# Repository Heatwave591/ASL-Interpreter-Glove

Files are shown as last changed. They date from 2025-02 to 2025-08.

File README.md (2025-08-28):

**Project Goals:**
* Design an American Sign Language (ASL) interpreting glove that converts sign language to English and outputs the translation.
* Recognize and translate the entire ASL alphabet.
* Identify and process basic static signs.
* Design a PCB for the circuit.

**Necessary Equipment and Sensors:**
* [ESP32 microcontroller x 2](https://www.amazon.com/HiLetgo-ESP-WROOM-32-Development-Microcontroller-Integrated/dp/B0718T232Z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)
* [Flex sensors x 15](https://www.amazon.com/dp/B00LP25V1A?ref=ppx_yo2ov_dt_b_fed_asin_title&th=1)
* [MPU6050 x 2](https://www.amazon.com/dp/B0BLGT1F5F?ref=ppx_yo2ov_dt_b_fed_asin_title)
* [Pair of gloves x 1](https://www.amazon.com/Cotton-Gloves-Handling-Inspection-Photography/dp/B07ZMXNCQ5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)

  Note - The links for the products are embedded in the text. Clicking the link will redirect you to amazon.com.

# Project Description
The ASL-interpreting glove will be designed to detect hand gestures and translate them into spoken words and a visual interface output. The system will consist of flex sensors to track finger movements, MPU6050 sensors for motion detection, and ESP32 microcontrollers to process and transmit data to an output system.
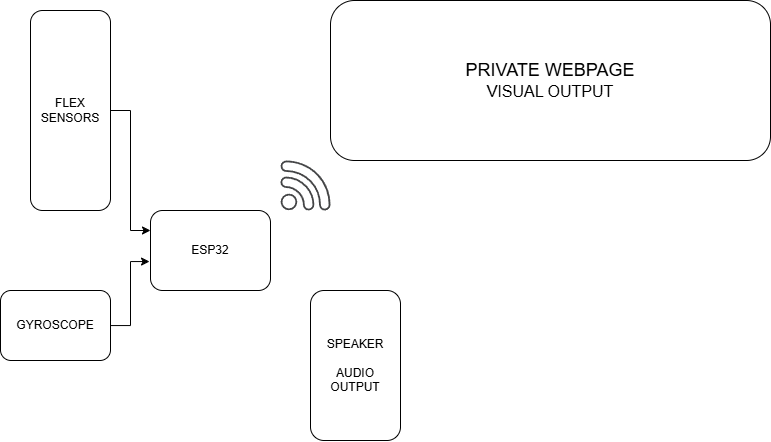
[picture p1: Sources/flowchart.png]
Glove Prototype


# System Setup
### Hardware
- The hardware consists of five flex sensors and an IMU in each hand
- The flex sensors need to be connected to the analog pins of the ESP32. Make sure to choose the correct pins according to your circuit.
	- All the ESP32 models do not have analog pins. If that happens, check the datasheet of the ESP32 and use the ADC pins instead and you should be good to go.
	- Many ESP32 boards have the issue of some pins being rendered useless when the wifi module is on. If the pin that is needed is being used by wifi, then, you have no choice other than using a different pin.
	
- The flex sensors need to create a conventional voltage divider circuit with the same value of resistors across all sensors (We have used the 10KOhm Resistor).
- The IMU follows a straight forward serial connection. 
	- Connect the power rails together
	- Connect the Serial Clock and the Serial Data of the IMU to the Serial Clock and Serial Data of the ESP32 respectively
- This concludes the hardware setup of the glove.

### Software 
The software consists of 4 parts.
- Arduino IDE Setup
- Firebase Setup
- Arduino Execution 
- HTML Setup and Execution

#### Arduino IDE Setup
- Download the Arduino IDE.
- Open the IDE.
- To make the ESP32 compatable, go to File > Preferences
- Paste this link in the Additional Board Manager URL's box
	- "https://raw.githubusercontent.com/espressif/arduino-esp32/gh-pages/package_esp32_index.json"
- Restart the IDE
- Go to Boards Manager and download the ESP32 package.
- Install the following libraries.
	- WiFi.h
	- Firebase_ESP_Client.h
	- Adafruit mpu6050
	- Adafruit Unified Sensor
	- Adafruit BusIO

- We will be using 2 scripts in this approach, but technically, there are many scripts in the repository that follow different methods that result in the same results.
- The process that we followed for this project is to essentially fetch data from the sensors, package the data into a JSON file, send it to a Firebase server and have the HTML file scrap data from there.

#### Firebase Setup
- Open Firebase in your browser.
- Login using your Google account.
- Go to Console.
- Create a new Firebase Project.
- Name your Project whatever you want. We have called it "ASL-Interpreter-Glove"
- Follow the instruction on screen and create the project.
- Enter the project.
- In the right side, Navigate to Product Categories > Build > Realtime Database.
- This is where our data will be seen.
- The link that is seen on top is our "DATABASE_URL". We will need this.
- Go to the project settings on the top right corner of the page.
- We will need the "API_KEY".
- This concludes the firebase setup. Missing out on any of these steps will result in the code not working.

#### Arduino Execution
- Open up the Arduino Editor.
- Since we have 2 gloves, we will have to upload and run 2 different codes on 2 ESP32s. But first, some modifications must be made to the code so that it will be compatible with the computer and the server.
- The changes are the same for both the codes.
- Set up the wifi network in the code
	- I have put placeholder values for the SSID and passwords for safety. This needs to be changed prior to running.
	- Replace WIFI_SSID and WIFI_PASSWORD with your credentials. Make sure that the network is in the 2.4GHz band 
	- Replace API_KEY and DATABASE_URL with the information we got from the firebase server.
- Once all of this is done, the code is ready to be dumped in the ESP32
- For the left hand and up and load [Firebase_Flex_Left.ino](Firebase%20Stuff/Firebase_Flex_Right/Firebase_Flex_Right.ino)
- Do the same with [Firebase_Flex_Right.ino](Firebase%20Stuff/Firebase_Flex_Right/Firebase_Flex_Right.ino) for the ESP32 that goes on the Right hand.

#### HTML Setup and Execution
- Once the server is up and running, We will have to setup the webpage where the inferences will be shown.
- Download the [webserver.html](webserver.html) file.
- Make the changes in lines 192, 193, 194 with the API_KEY, DATABASE_URL and PROJECT_ID.
- Now, host the file with python. (Note that you will not need a separate python script to do this. It can be done in the python interactive terminal by following these setps)
	- Go to the file directory and open a python interactive terminal.
	- Run this code  ``` python3 -m SimpleHTTPServer 3000```
	- This will locally host the webpage.
	- Open the web browser and type ```localhost:3000 ```
	- The port used here is 3000, this can be changed to any other port too.

# Machine Learning Model Interpretation
- The machine learning model runs by taking data out of the serial ports.
- When the ESP32 is executing the code, close all the serial monitors and then run the python sctript [INT_model_inference.py](Interpretation/INT_model_inference.py).
- This will run the machine learning model and send inferences to the webpage.

# Possible Future Works
* Support for dynamic signs.
* Integration of two gloves for improved accuracy.

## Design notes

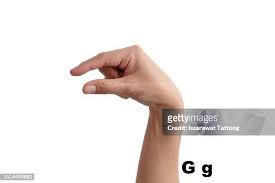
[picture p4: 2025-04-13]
Submissions/Final/Final Video/srcs/gg.jpeg

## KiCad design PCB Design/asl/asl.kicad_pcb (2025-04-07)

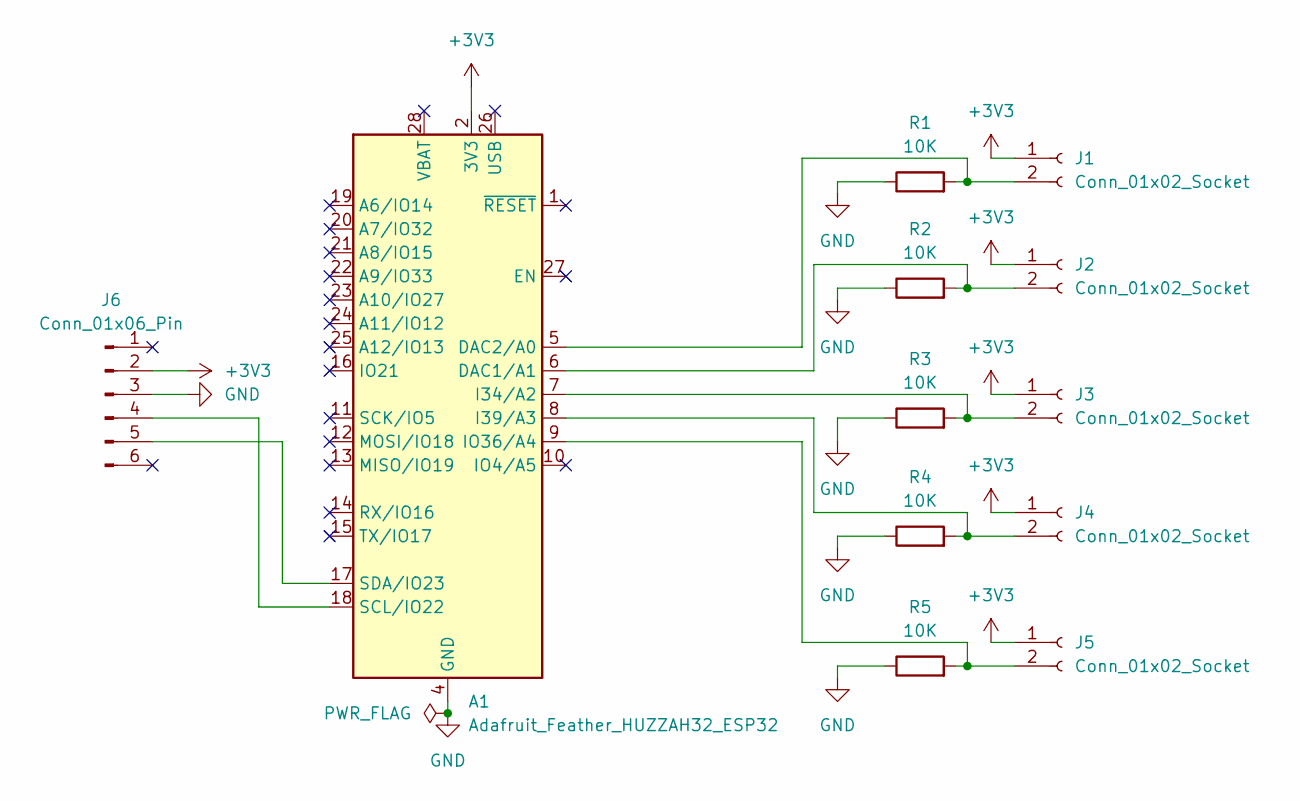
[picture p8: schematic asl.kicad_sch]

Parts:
A1: Adafruit_Feather_HUZZAH32_ESP32; Adafruit_Feather
J1, J2, J3, J4, J5: Conn_01x02_Socket; TerminalBlock_bornier-2_P5.08mm
J6: Conn_01x06_Pin; PinSocket_1x06_P2.54mm_Vertical
R1, R2, R3, R4, R5: 10K; R_Axial_DIN0207_L6.3mm_D2.5mm_P7.62mm_Horizontal

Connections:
+3V3: A1.2 (3V3), J1.1, J2.1, J3.1, J4.1, J5.1, J6.2
GND: A1.4 (GND), J6.3, R1.1, R2.1, R3.1, R4.1, R5.1
unnamed: A1.6 (DAC1/A1), J2.2, R2.2
unnamed: A1.5 (DAC2/A0), J1.2, R1.2
unnamed: A1.7 (I34/A2), J3.2, R3.2
unnamed: A1.8 (I39/A3), J4.2, R4.2
unnamed: A1.9 (IO36/A4), J5.2, R5.2
unnamed: A1.18 (SCL/IO22), J6.4
unnamed: A1.17 (SDA/IO23), J6.5

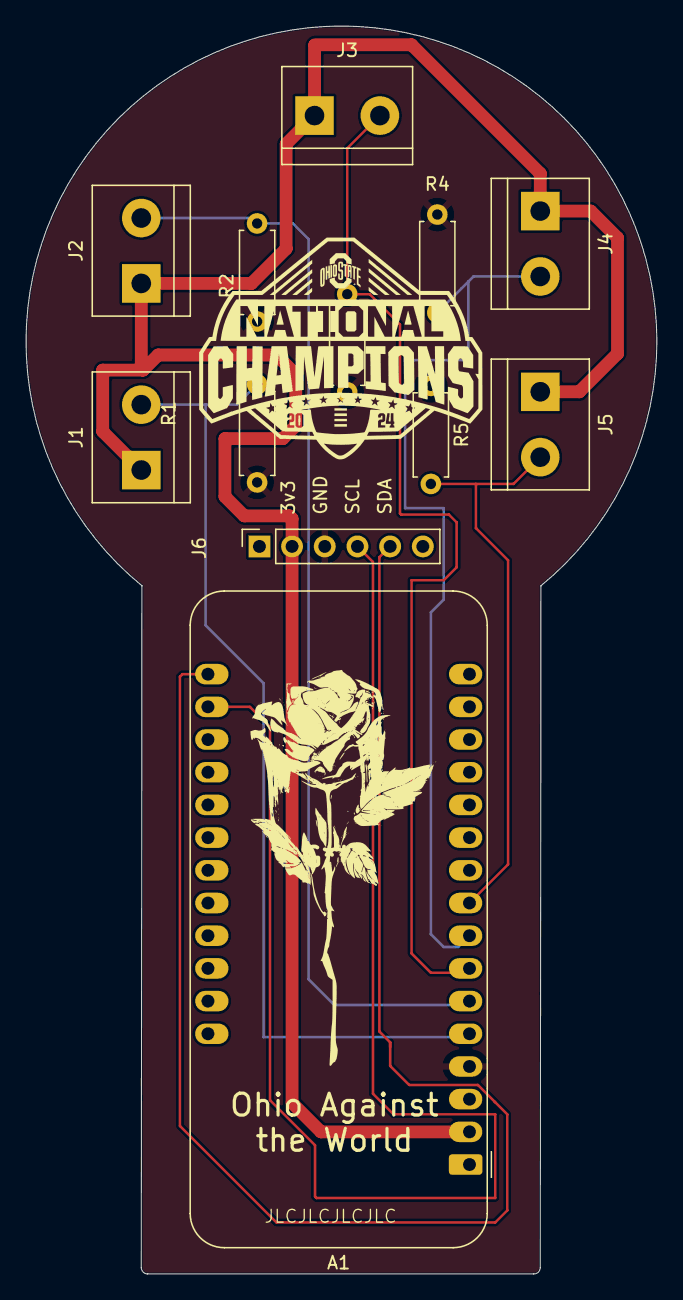
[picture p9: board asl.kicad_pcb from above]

Board: 2 copper layers, 49.0 x 97.0 mm, 12 parts (0 on the bottom side), 9 nets.

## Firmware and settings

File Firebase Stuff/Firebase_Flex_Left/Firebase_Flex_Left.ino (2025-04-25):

// Om Namo Narayana

#include <WiFi.h>
#include <Firebase_ESP_Client.h>

#include "addons/TokenHelper.h"
#include "addons/RTDBHelper.h"

#include <Adafruit_MPU6050.h>
#include <Adafruit_Sensor.h>
#include <Wire.h>

Adafruit_MPU6050 mpu;

#define WIFI_SSID "SSID here"
#define WIFI_PASSWORD "Wifi password here"

//Change this and we are FUCKED
#define API_KEY "API Key here"
#define DATABASE_URL "Database URL here"

const int F1 = A0; 
const int F2 = A1; 
const int F3 = A2; 
const int F4 = A3; 
const int F5 = A4; 

int f_volt1;
int f_volt2;
int f_volt3;
int f_volt4;
int f_volt5;

float gyroX, gyroY, gyroZ;
float accX, accY, accZ, accNet; 
float tempr;

FirebaseData fbdo;
FirebaseAuth auth;
FirebaseConfig config;

String uid;
String databasePath;
String predictedLetter = "-";

unsigned long sendDataPrevMillis = 0;

// === Character Range Detection Struct ===
struct FingerRange {
  int minVal[5];
  int maxVal[5];
  char letter;
};

FingerRange letterModels[] = {
  {{100, 117, 93, 107, 0}, {2906, 3042, 2415, 2295, 0}, 'a'},
  {{0, 0, 0, 0, 500}, {0, 199, 0, 0, 2500}, 'b'},
  {{0, 0, 0, 205, 0}, {0, 0, 0, 1500, 0}, 'f'},
  {{150, 150, 135, 0, 0}, {2000, 2467, 1899, 0, 0}, 'g'},
  {{0, 377, 402, 169, 117}, {0, 2615, 2037, 2309, 1238}, 'i'},
  {{23, 441, 194, 13, 100}, {1847, 2023, 1628, 1652, 1863}, 'o'},
  {{48, 500, 0, 0, 300}, {2134, 2134, 0, 0, 1600}, 'v'},
  {{0, 63, 13, 45, 0}, {0, 1961, 1550, 1677, 0}, 'y'},
  {{0, 100, 100, 0, 0}, {0, 2726, 2632, 0, 0}, 'k'},   //ILY
  {{0, 0, 0, 0, 10}, {0, 0, 0, 0, 500}, 'l'},   //fine
  {{100, 107, 93, 0, 30}, {2906, 3000, 2415, 0, 3042}, 'm'} //point
};

const int modelCount = sizeof(letterModels) / sizeof(letterModels[0]);

char inferLetterFromRange(int pinky, int ring, int middle, int index, int thumb) {
  for (int i = 0; i < modelCount; i++) {
    bool match = true;
    for (int j = 0; j < 5; j++) {
      int val;
      switch(j) {
        case 0: val = thumb; break;
        case 1: val = index; break;
        case 2: val = middle; break;
        case 3: val = ring; break;
        case 4: val = pinky; break;
      }

      int minVal = letterModels[i].minVal[j];
      int maxVal = letterModels[i].maxVal[j];

      // Add 10% margin below min and 15% margin above max
      int extendedMin = minVal - (minVal * 15) / 100;
      int extendedMax = maxVal + (maxVal * 15) / 100;

      if (val < extendedMin || val > extendedMax) {
        match = false;
        break;
      }
    }

    if (match) return letterModels[i].letter;
  }
  return '-';
}



void setup() {
  Serial.begin(115200);
  randomSeed(analogRead(A5));

  // same ass boring wifi connection shii
  WiFi.begin(WIFI_SSID, WIFI_PASSWORD);
  Serial.print("Connecting to WiFi");

  while (WiFi.status() != WL_CONNECTED) {
    Serial.print(".");
    delay(300);
  }
  
  Serial.println();
  Serial.print("Connected with IP: ");
  Serial.println(WiFi.localIP());
  
  
  config.api_key = API_KEY;
  config.database_url = DATABASE_URL;

  if (Firebase.signUp(&config, &auth, "", "")) {
    Serial.println("ESP is in");
    uid = auth.token.uid.c_str();
  } else {
    Serial.printf("ESP didn't get connected. The fuckup is here:", config.signer.signupError.message.c_str());
  }

  // Gyroscope searching 
  // if (!mpu.begin()) {
  //   Serial.println("Failed to find MPU6050 chip");
  //   while (1) {
  //     delay(10);
  //   }
  // }

  // // MPU6050 setup
  // // Do not change this snippet
  // mpu.setAccelerometerRange(MPU6050_RANGE_8_G);
  // switch (mpu.getAccelerometerRange()) {
  //   case MPU6050_RANGE_2_G:
  //     Serial.println("+-2G");
  //     break;
  //   case MPU6050_RANGE_4_G:
  //     Serial.println("+-4G");
  //     break;
  //   case MPU6050_RANGE_8_G:
  //     Serial.println("+-8G");
  //     break;
  //   case MPU6050_RANGE_16_G:
  //     Serial.println("+-16G");
  //     break;
  //   }
  //   mpu.setGyroRange(MPU6050_RANGE_500_DEG);
  //   Serial.print("Gyro range set to: ");
  //   switch (mpu.getGyroRange()) {
  //   case MPU6050_RANGE_250_DEG:
  //     Serial.println("+- 250 deg/s");
  //     break;
  //   case MPU6050_RANGE_500_DEG:
  //     Serial.println("+- 500 deg/s");
  //     break;
  //   case MPU6050_RANGE_1000_DEG:
  //     Serial.println("+- 1000 deg/s");
  //     break;
  //   case MPU6050_RANGE_2000_DEG:
  //     Serial.println("+- 2000 deg/s");
  //     break;
  //   }

  //   mpu.setFilterBandwidth(MPU6050_BAND_5_HZ);
  //   Serial.print("Filter bandwidth set to: ");
  //   switch (mpu.getFilterBandwidth()) {
  //   case MPU6050_BAND_260_HZ:
  //     Serial.println("260 Hz");
  //     break;
  //   case MPU6050_BAND_184_HZ:
  //     Serial.println("184 Hz");
  //     break;
  //   case MPU6050_BAND_94_HZ:
  //     Serial.println("94 Hz");
  //     break;
  //   case MPU6050_BAND_44_HZ:
  //     Serial.println("44 Hz");
  //     break;
  //   case MPU6050_BAND_21_HZ:
  //     Serial.println("21 Hz");
  //     break;
  //   case MPU6050_BAND_10_HZ:
  //     Serial.println("10 Hz");
  //     break;
  //   case MPU6050_BAND_5_HZ:
  //     Serial.println("5 Hz");
  //     break;
  //   }
    
    // MPU6050 initialization ends here

  config.token_status_callback = tokenStatusCallback; 

  Firebase.begin(&config, &auth);
  Firebase.reconnectWiFi(true);

  databasePath = "/flex_sensors_Left";
}

void loop() {
  if (Firebase.ready() && (millis() - sendDataPrevMillis > 2500 || sendDataPrevMillis == 0)) {
    sendDataPrevMillis = millis();
    
    f_volt1 = analogRead(A0);
    f_volt2 = analogRead(A1);
    f_volt3 = analogRead(A2);
    f_volt4 = analogRead(A3);
    f_volt5 = analogRead(A4);

    // sensors_event_t a, g, temp;
    // mpu.getEvent(&a, &g, &temp);
    
    // gyroX = g.gyro.x;
    // gyroY = g.gyro.y;
    // gyroZ = g.gyro.z;

    // accX = a.acceleration.x;
    // accY = a.acceleration.y;
    // accZ = a.acceleration.z;
    // accNet = (sqrt(sq(accX)+sq(accY)+sq(accZ)));

    // tempr = temp.temperature;

    Serial.print("Finger 1: ");
    Serial.print(f_volt1);
    Serial.print("\t"); 

    Serial.print("Finger 2: ");
    Serial.print(f_volt2);
    Serial.print("\t");

    Serial.print("Finger 3: ");
    Serial.print(f_volt3);
    Serial.print("\t");

    Serial.print("Finger 4: ");
    Serial.print(f_volt4);
    Serial.print("\t");

    Serial.print("Finger 5: ");
    Serial.print(f_volt5);
    Serial.println();

    // Predict character based on finger range logic
    char predicted = inferLetterFromRange(f_volt1, f_volt2, f_volt3, f_volt4, f_volt5);
    predictedLetter = String(predicted);

    Serial.print("Predicted letter: ");
    Serial.println(predicted);

    f_volt1 = random(1024);
    f_volt2 = random(1024);
    f_volt3 = random(1024);
    f_volt4 = random(1024);
    f_volt5 = random(1024);
    
    FirebaseJson json;

    // This is the same testing code from
    // some of the other files.
    // Remove this while using sensors

    json.set("finger1", f_volt1);
    json.set("finger2", f_volt2);
    json.set("finger3", f_volt3);
    json.set("finger4", f_volt4);
    json.set("finger5", f_volt5);
    // json.set("Gyroscope X", gyroX);
    // json.set("Gyroscope Y", gyroY);
    // json.set("Gyroscope Z", gyroZ);
    // json.set("Net Acceleration", accNet);
    // json.set("Tempreture", tempr);
    json.set("Predicted Letter", predictedLetter);

    //Testing code ends here

    // Don't mess with this part of the code.
    // It is something i scouted out from github
    // I still don't completely understand what's going on here.
    // For some reason, line 127 and 128 is necessary, no idea why

    String latestPath = databasePath;
    // String historyPath = databasePath + "/history/" + String(millis());

    if (Firebase.RTDB.setJSON(&fbdo, latestPath.c_str(), &json)) {
      Serial.println("GGWP");
    } else {
      Serial.println("Kal");
      Serial.println(": " + fbdo.errorReason());
    }
    
  }
}

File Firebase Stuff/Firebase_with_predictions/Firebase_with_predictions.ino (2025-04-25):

#include <WiFi.h>
#include <Firebase_ESP_Client.h>

// Provide the token generation process info
#include <addons/TokenHelper.h>
// Provide the RTDB payload printing info
#include <addons/RTDBHelper.h>

// WiFi credentials
#define WIFI_SSID "SSID here"
#define WIFI_PASSWORD "Wifi password here"

// Firebase project settings
#define API_KEY "API Key here"
#define DATABASE_URL "Database URL here"

// Define Firebase Data object, auth and config
FirebaseData fbdo;
FirebaseAuth auth;
FirebaseConfig config;

// Pin definitions for flex sensors - ESP32 pins
const int F1 = 37; // VP - ADC1_CH0
const int F2 = 33; // VN - ADC1_CH3
const int F3 = A2; // ADC1_CH6
const int F4 = A3; // ADC1_CH7
const int F5 = A4; // ADC1_CH4

int nig;
int ler;
int f_volt3;
int f_volt4;
int f_volt5;

String predictedLetter = "-";
unsigned long sendDataPrevMillis = 0;
bool signupOK = false;

struct FingerRange {
  int minVal[5];
  int maxVal[5];
  char letter;
};

FingerRange letterModels[] = {
  {{100, 117, 93, 107, 0}, {2906, 3042, 2415, 2295, 0}, 'a'},
  {{0, 0, 0, 0, 500}, {0, 199, 0, 0, 2500}, 'b'},
  // {{76, 77, 73, 78, 0}, {1424, 1885, 1185, 995, 0}, 'c'},  
  // {{50, 50, 50, 0, 0}, {1854, 1500, 1300, 0, 0}, 'd'},
  // {{453, 1680, 1111, 859, 380}, {1967, 2470, 1671, 1855, 1828}, 'e'},
  {{0, 0, 0, 205, 0}, {0, 0, 0, 1500, 0}, 'f'},
  {{150, 150, 135, 0, 0}, {2000, 2467, 1899, 0, 0}, 'g'},
  // {{150, 150, 0, 0, 0}, {2303, 1924, 0, 0, 0}, 'h'},
  {{0, 377, 402, 169, 117}, {0, 2615, 2037, 2309, 1238}, 'i'},
  // {{29, 308, 0, 0, 0}, {1870, 1136, 0, 0, 0}, 'k'},
  // {{111, 111, 111, 0, 17}, {1421, 2294, 1719, 0, 987}, 'l'},
  // {{214, 1296, 244, 51, 2}, {2183, 2339, 1392, 1279, 1150}, 'm'},
  // {{64, 228, 138, 146, 39}, {2093, 2493, 1408, 1117, 1488}, 'n'},
  {{23, 441, 194, 13, 100}, {1847, 2023, 1628, 1652, 1863}, 'o'},
  // {{91, 32, 0, 0, 0}, {1492, 1657, 0, 0, 0}, 'p'},
  // {{221, 1793, 586, 0, 0}, {1761, 2533, 1900, 0, 6}, 'q'},
  // {{159, 772, 0, 64, 0}, {2154, 2163, 1143, 1078, 626}, 'r'},
  // {{71, 1424, 43, 400, 6}, {2377, 2293, 1792, 1233, 1251}, 's'},
  // {{113, 305, 343, 31, 54}, {1794, 1385, 1600, 894, 1387}, 't'},
  // {{33, 291, 0, 0, 0}, {2076, 1774, 0, 0, 0}, 'u'},
  {{48, 500, 0, 0, 300}, {2134, 2134, 0, 0, 1600}, 'v'},
  // {{90, 0, 0, 0, 00}, {2500, 0, 0, 0, 2600}, 'w'},
  // {{31, 941, 133, 0, 158}, {1614, 2559, 1607, 961, 1271}, 'x'},
  {{0, 63, 13, 45, 0}, {0, 1961, 1550, 1677, 0}, 'y'},
  {{0, 100, 100, 0, 0}, {0, 2726, 2632, 0, 0}, 'k'},   //ILY
  {{0, 0, 0, 0, 10}, {0, 0, 0, 0, 500}, 'l'},   //fine
  {{100, 107, 93, 0, 30}, {2906, 3000, 2415, 0, 3042}, 'm'} //point
};
const int modelCount = sizeof(letterModels) / sizeof(letterModels[0]);

char inferLetterFromRange(int pinky, int ring, int middle, int index, int thumb) {
  for (int i = 0; i < modelCount; i++) {
    bool match = true;
    for (int j = 0; j < 5; j++) {
      int val;
      switch(j) {
        case 0: val = thumb; break;
        case 1: val = index; break;
        case 2: val = middle; break;
        case 3: val = ring; break;
        case 4: val = pinky; break;
      }

      int minVal = letterModels[i].minVal[j];
      int maxVal = letterModels[i].maxVal[j];

      // Add 15% margin below min and above max
      int extendedMin = minVal - (minVal * 15) / 100;
      int extendedMax = maxVal + (maxVal * 15) / 100;

      if (val < extendedMin || val > extendedMax) {
        match = false;
        break;
      }
    }

    if (match) return letterModels[i].letter;
  }
  return '-';
}

void connectWiFi() {
  Serial.print("Connecting to WiFi");
  WiFi.begin(WIFI_SSID, WIFI_PASSWORD);
  
  while (WiFi.status() != WL_CONNECTED) {
    Serial.print(".");
    delay(300);
  }
  
  Serial.println();
  Serial.print("Connected with IP: ");
  Serial.println(WiFi.localIP());
}

void setup() {
  Serial.begin(115200);
  
  // Set the ADC resolution to 12 bits (0-4095)
  analogReadResolution(12);
  
  // Connect to WiFi
  connectWiFi();
  
  // Assign the API key
  config.api_key = API_KEY;

  // Assign the RTDB URL
  config.database_url = DATABASE_URL;

  // Sign up
  if (Firebase.signUp(&config, &auth, "", "")) {
    Serial.println("Firebase signup OK");
    signupOK = true;
  } else {
    Serial.printf("Firebase signup failed: %s\n", config.signer.signupError.message.c_str());
  }

  // Assign the callback function for the long running token generation task
  config.token_status_callback = tokenStatusCallback; // see addons/TokenHelper.h
  
  // Begin connection
  Firebase.begin(&config, &auth);
  Firebase.reconnectWiFi(true);
  
  Serial.println("Firebase setup complete!");
}

void loop() {
  // Read flex sensor values
  nig = analogRead(F1);
  ler = analogRead(F2);
  f_volt3 = analogRead(F3);
  f_volt4 = analogRead(F4);
  f_volt5 = analogRead(F5);

  // if(nig > 200) {
  //   nig += 1000;
  // }

  // if(ler > 200) {
  //   ler += 1000;
  // }

  // Debug output
  Serial.print("Finger 1: ");
  Serial.print(nig);
  Serial.print("\t"); 

  Serial.print("Finger 2: ");
  Serial.print(ler);
  Serial.print("\t");

  Serial.print("Finger 3: ");
  Serial.print(f_volt3);
  Serial.print("\t");

  Serial.print("Finger 4: ");
  Serial.print(f_volt4);
  Serial.print("\t");

  Serial.print("Finger 5: ");
  Serial.print(f_volt5);
  Serial.print("\t");

  // Predict letter based on sensor values
  char predicted = inferLetterFromRange(nig, ler, f_volt3, f_volt4, f_volt5);

  if (predicted != '-') {
    predictedLetter = String(predicted);
  }

  Serial.print("Predicted letter: ");
  Serial.println(predictedLetter);

  // Only send data if Firebase signup was successful
  if (signupOK && Firebase.ready() && (millis() - sendDataPrevMillis > 1000 || sendDataPrevMillis == 0)) {
    sendDataPrevMillis = millis();
    
    // Write sensor values to Firebase
    Firebase.RTDB.setInt(&fbdo, "signLanguageData/finger1", nig);
    Firebase.RTDB.setInt(&fbdo, "signLanguageData/finger2", ler);
    Firebase.RTDB.setInt(&fbdo, "signLanguageData/finger3", f_volt3);
    Firebase.RTDB.setInt(&fbdo, "signLanguageData/finger4", f_volt4);
    Firebase.RTDB.setInt(&fbdo, "signLanguageData/finger5", f_volt5);

    if(predictedLetter == "k"){
      Firebase.RTDB.setString(&fbdo, "signLanguageData/predictedLetter", "I Love You");
    }

    else if(predictedLetter == "l")
    {
      Firebase.RTDB.setString(&fbdo, "signLanguageData/predictedLetter", "Fine");
    }

    else if(predictedLetter == "m")
    {
      Firebase.RTDB.setString(&fbdo, "signLanguageData/predictedLetter", "Point");
    }

    else
    {
      Firebase.RTDB.setString(&fbdo, "signLanguageData/predictedLetter", predictedLetter);
    }
    
    Firebase.RTDB.setInt(&fbdo, "signLanguageData/timestamp", millis());
    
    Serial.println("Firebase update successful");
  }
}

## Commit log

2025-02-26 update flex_sensor: 5 sensors
2025-03-03 create webserver_SPIFFS and flex
    [flex.ino, webserver_SPIFFS.ino]
2025-03-17 Added gyro to firebase right
2025-03-31 Create PCB Schematic and Layout
    [asl.kicad_pcb, asl.kicad_sch]
2025-03-31 Added CSVs for 10 datasets of 10 values each
    [ILY.csv, a.csv, b.csv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]
2025-04-01 Added 10 more samples per dataset
    [ILY.csv, a.csv, b.csv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]
2025-04-01 Compiled datasets
    [compiledDatasets.csv]
2025-04-04 added more letters
    [compiledDatasets.csv]
2025-04-07 UPLOAD PCB Files
    [asl-B_Cu.gbr, asl-B_Mask.gbr, asl-B_Paste.gbr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]
2025-04-11 added some signs
    [compiledDatasets.csv]
2025-04-25 Update README.md
    changes 1KOhm resistor to 10KOhm resistor
